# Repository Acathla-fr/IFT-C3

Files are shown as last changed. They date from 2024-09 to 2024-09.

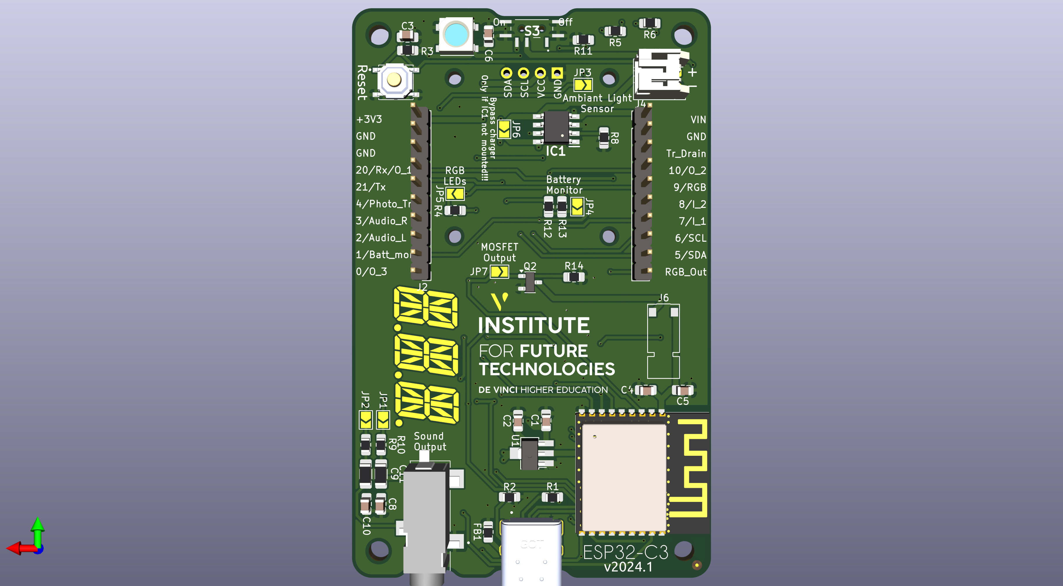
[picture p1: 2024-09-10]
IFT-C3_pcb_back.png

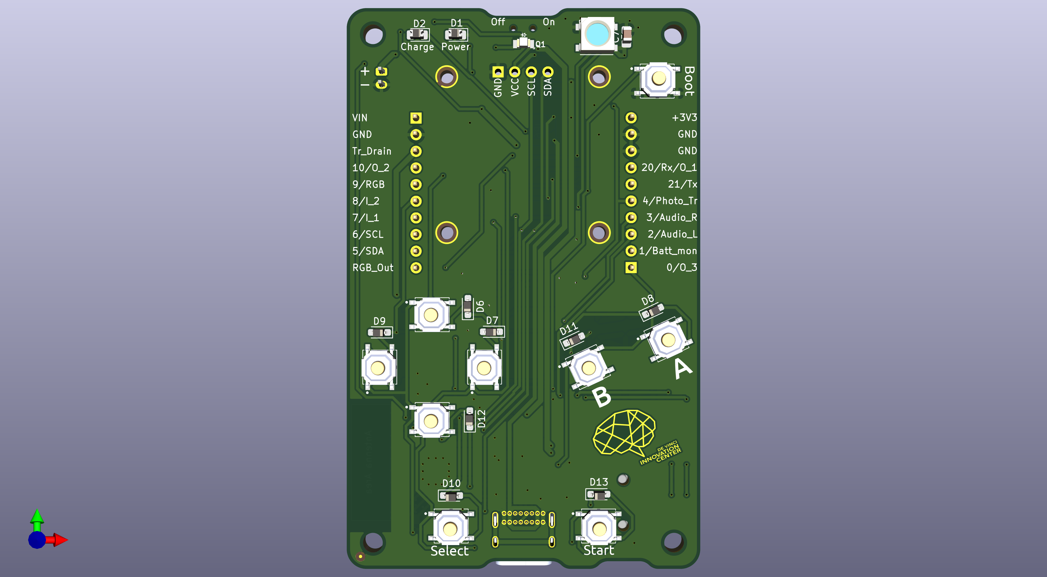
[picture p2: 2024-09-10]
IFT-C3_pcb_front.png

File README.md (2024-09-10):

# IFT-C3
Printed Circuit Board with an ESP32-C3. Version 2.1 (2024)

Version released for the new students. Now integrates the support for the OLED screen and the buttons.

BUGS!!! (fixed in the kicad design, not on the produced boards):

    Buttons pinout is wrong, you'll have to solder them rotated 25°. For the Boot/Start button, since I thought there was two buttons in one without verifying, you'll have to be creative to fix it (at least the start button, the boot can be selected with Dupont wires by connecting pin 9 to ground).
    Holes for the screen are too small, you'll have to replace the connector or be creative (file the pins works).

GPIO 0 is used by the keyboard matrix<br/>
GPIO 1 is used by the keyboard matrix and optionnaly for battery voltage measurement<br/>
GPIO 2 and 3 are optionnaly used for audio<br/>
GPIO 4 is optionnaly used for the light sensor or to control the MOSFET<br/>
GPIO 5 is used by the SDA line for the OLED screen<br/>
GPIO 6 is used by the SCL line for the OLED screen<br/>
GPIO 7 is used by the keyboard matrix<br/>
GPIO 8 is used by the keyboard matrix<br/>
GPIO 9 is plugged to the Boot button which can be used in your design. The reset button cannot.<br/>
GPIO 9 also optionnaly used for the RGBW LEDs<br/>
GPIO 10 is used by the keyboard matrix<br/>
GPIO 20 is used by the keyboard matrix but also as the Rx UART
GPIO 21 is used by Tx UART

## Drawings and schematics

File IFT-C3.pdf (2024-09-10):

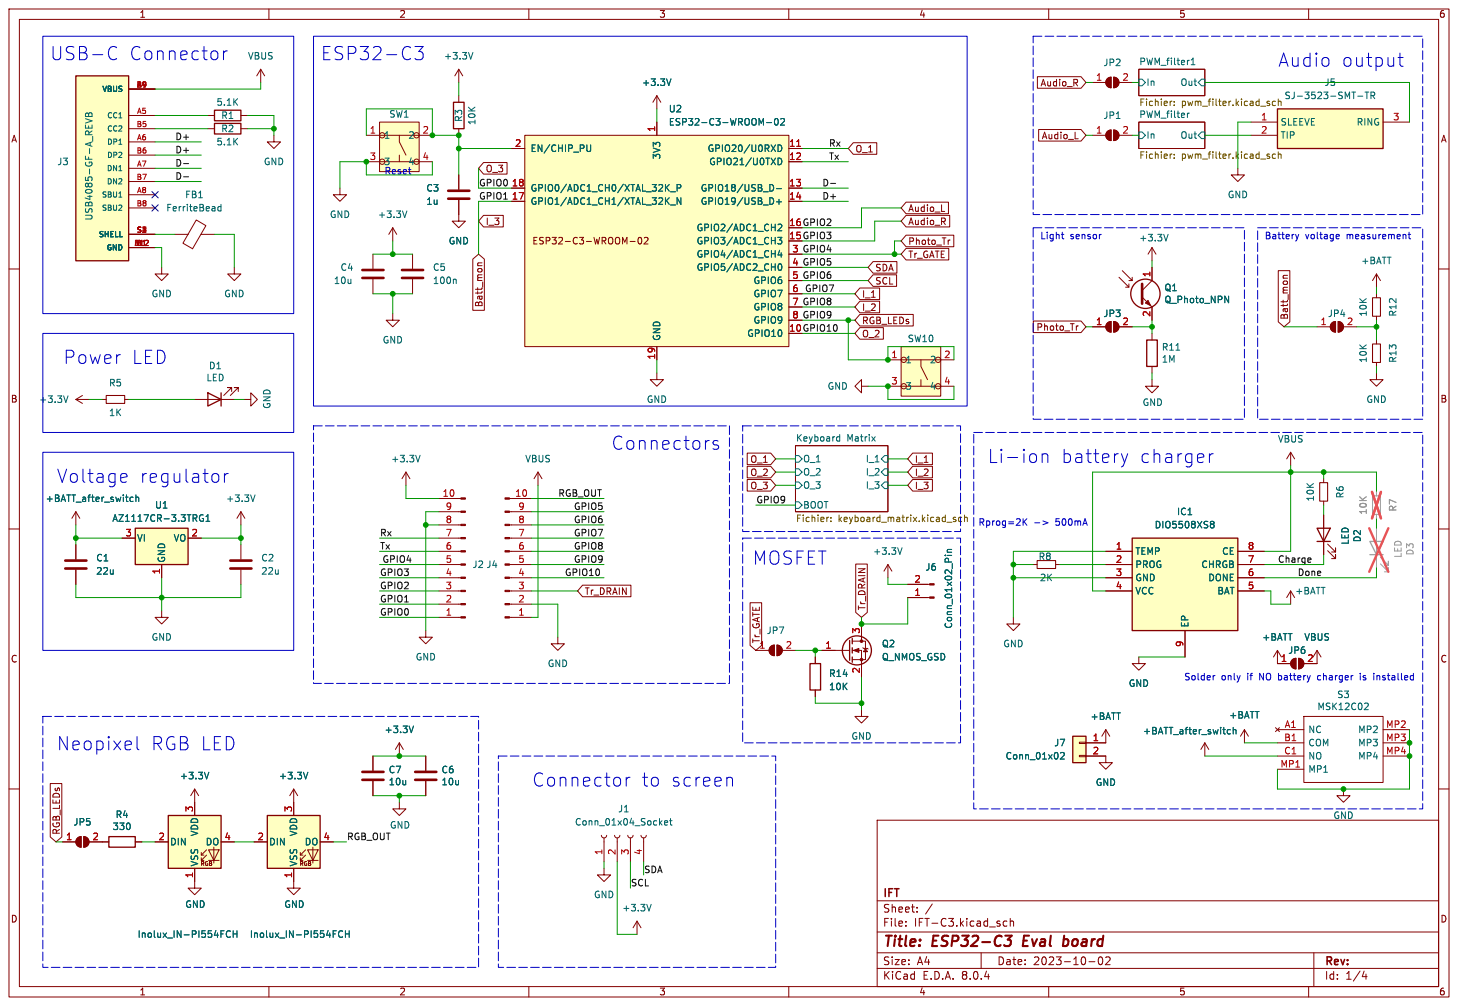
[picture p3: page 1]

J5 SJ-3523-SMT-TR GND

I_1 BOOT Keyboard Matrix Fichier: keyboard_matrix.kicad_sch C4

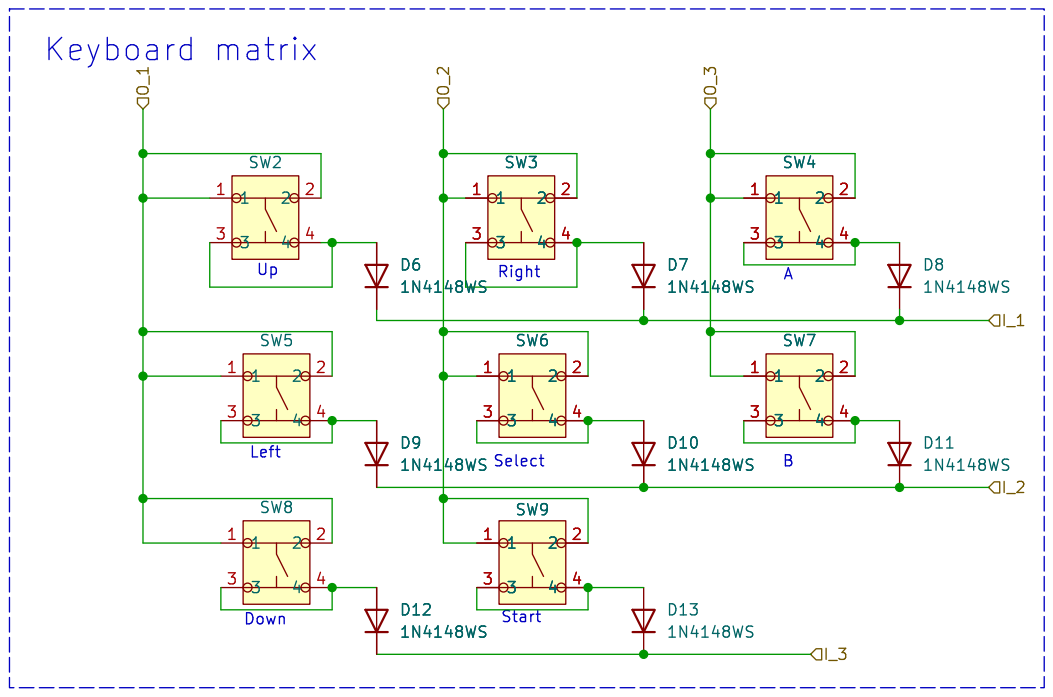
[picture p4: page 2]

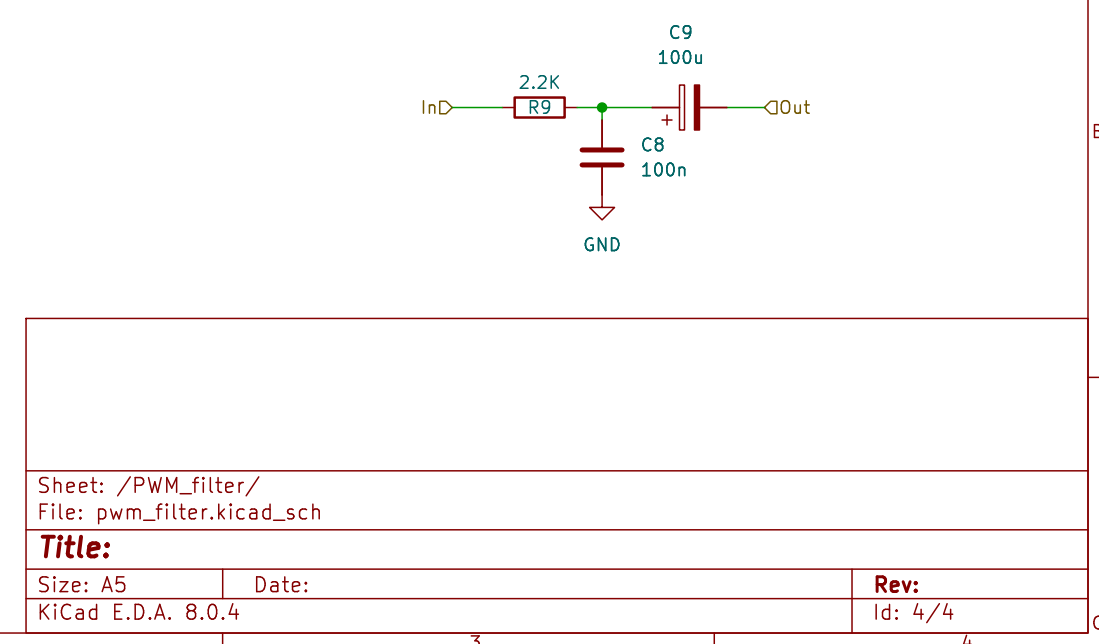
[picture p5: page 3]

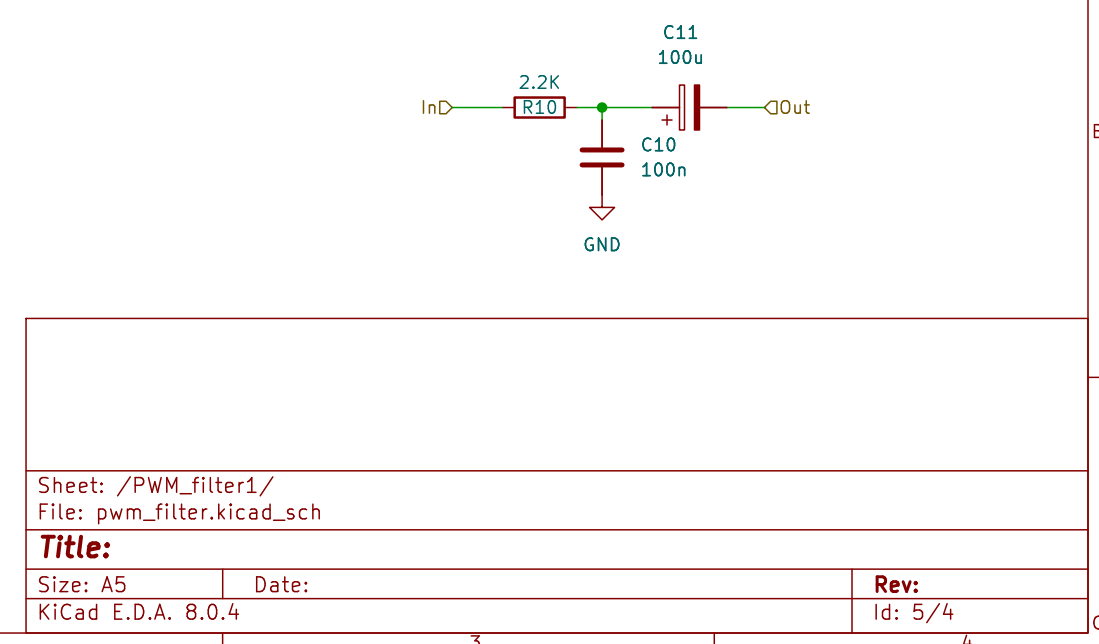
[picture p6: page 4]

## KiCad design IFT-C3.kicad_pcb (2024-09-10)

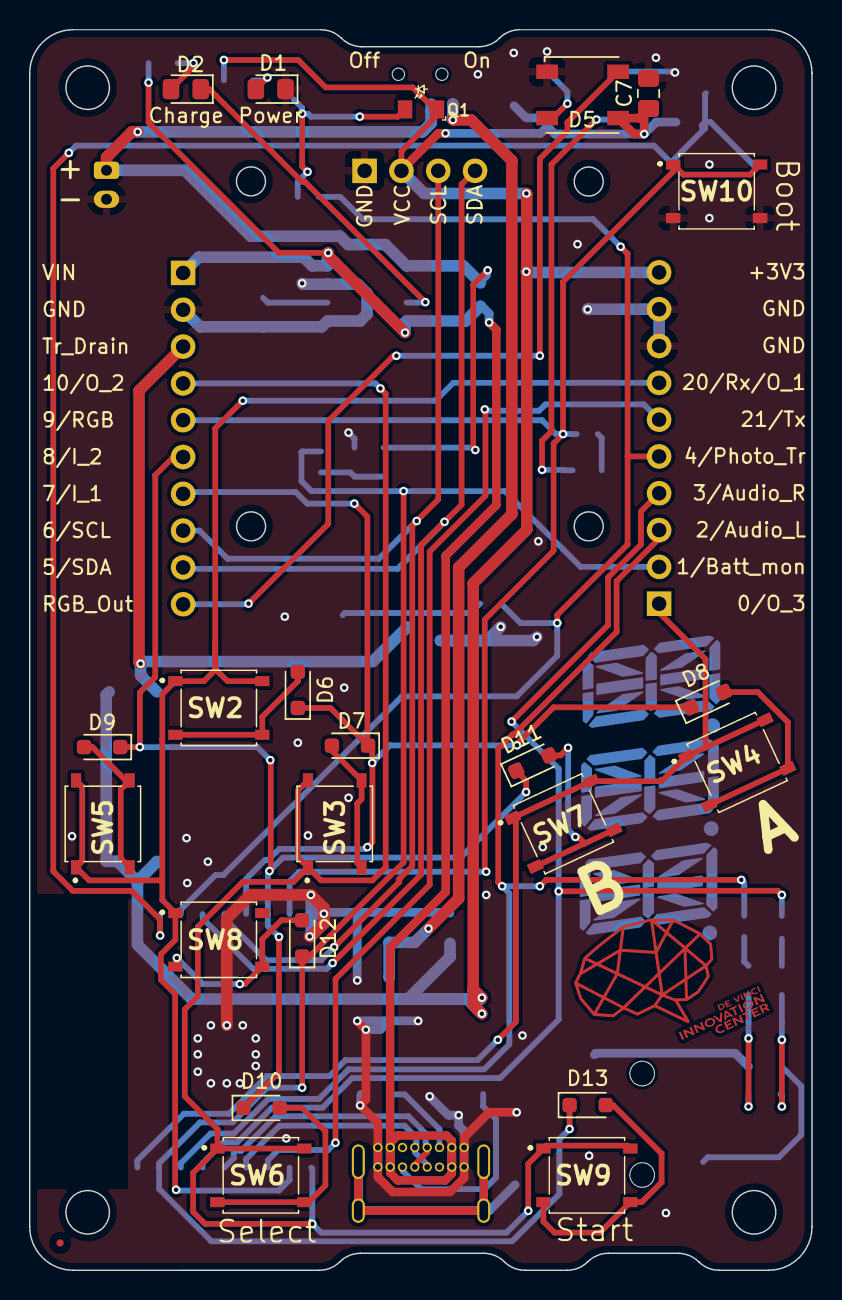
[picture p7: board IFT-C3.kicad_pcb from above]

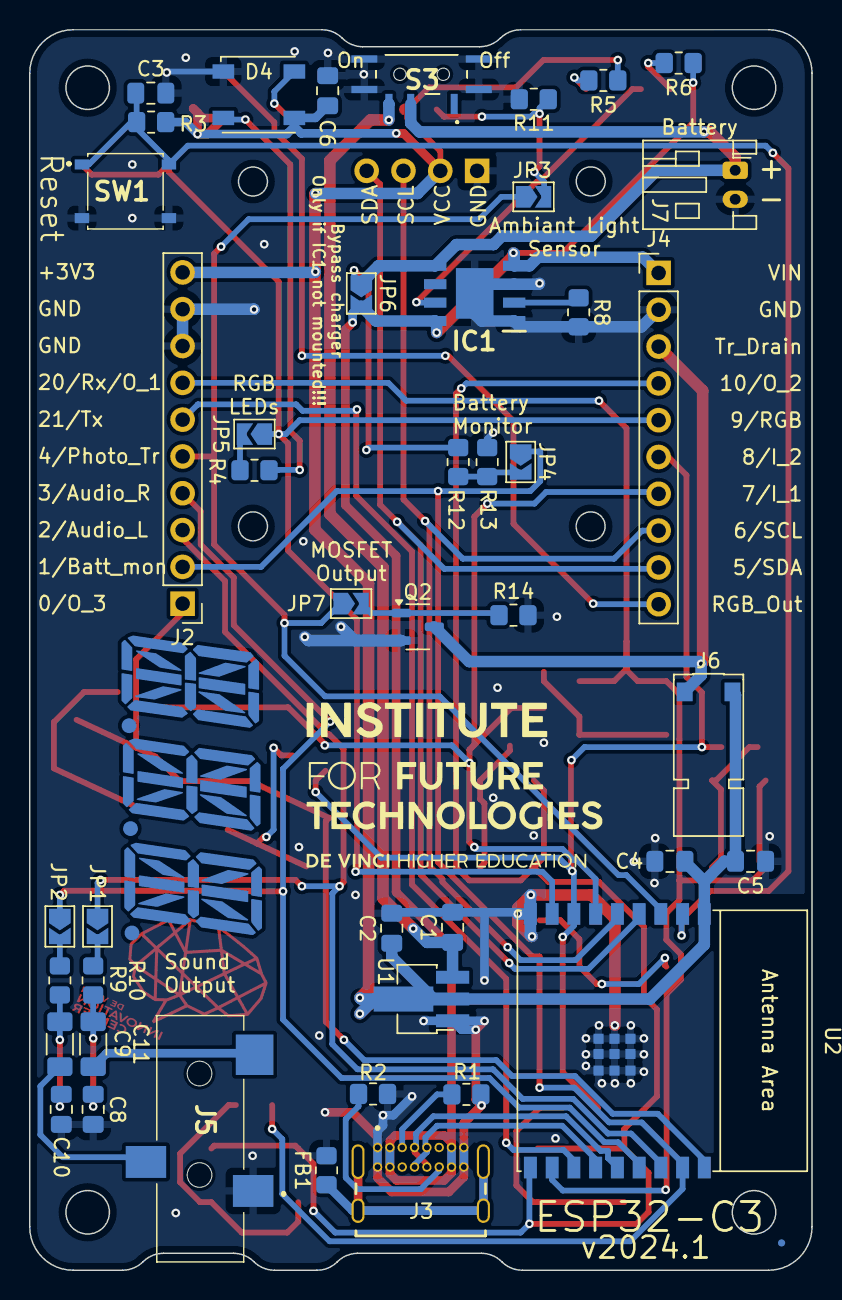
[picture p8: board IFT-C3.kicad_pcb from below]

Board: 2 copper layers, 54.0 x 85.6 mm, 70 parts (47 on the bottom side), 50 nets.

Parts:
C1, C2: 22u; C_0805_2012Metric_Pad1.18x1.45mm_HandSolder
C3: 1u; C_0805_2012Metric_Pad1.18x1.45mm_HandSolder
C4, C6, C7: 10u; C_0805_2012Metric_Pad1.18x1.45mm_HandSolder
C5, C8, C10: 100n; C_0805_2012Metric_Pad1.18x1.45mm_HandSolder
C9, C11: 100u; R_1206_3216Metric_Pad1.30x1.75mm_HandSolder
D1, D2: LED; D_0805_2012Metric_Pad1.15x1.40mm_HandSolder
D4, D5: Inolux_IN-PI554FCH; LED_Inolux_IN-PI554FCH_PLCC4_5.0x5.0mm_P3.2mm
D6, D7, D8, D9, D10, D11, D12, D13: 1N4148WS; D_SOD-323_HandSoldering
FB1: FerriteBead; R_0805_2012Metric_Pad1.20x1.40mm_HandSolder
G001, G001#2, G001#3: LOGO; segments
IC1: DIO5508XS8; SOIC127P600X170-9N
J1: Conn_01x04_Socket; SSD1306_module
J2, J4: Conn_01x10_Pin; PinHeader_1x10_P2.54mm_Vertical
J3: USB4085-GF-A_REVB; GCT_USB4085-GF-A_REVB
J5: SJ-3523-SMT-TR; SJ3523SMTTR
J6: Conn_01x02_Pin; Vybronics_VZ30C1T8219732L
J7: Conn_01x02; JST_PH_S2B-PH-K_1x02_P2.00mm_Horizontal
JP1, JP2, JP3, JP4, JP5, JP6, JP7: SolderJumper_2_Open; SolderJumper-2_P1.3mm_Open_TrianglePad1.0x1.5mm
Q1: Q_Photo_NPN; SFH3710
Q2: Q_NMOS_GSD; SOT-23-3
R1, R2: 5.1K; R_0805_2012Metric_Pad1.20x1.40mm_HandSolder
R3, R6, R12, R13, R14: 10K; R_0805_2012Metric_Pad1.20x1.40mm_HandSolder
R4: 330; R_0805_2012Metric_Pad1.20x1.40mm_HandSolder
R5: 1K; R_0805_2012Metric_Pad1.20x1.40mm_HandSolder
R8: 2K; R_0805_2012Metric_Pad1.20x1.40mm_HandSolder
R9, R10: 2.2K; R_0805_2012Metric_Pad1.20x1.40mm_HandSolder
R11: 1M; R_0805_2012Metric_Pad1.20x1.40mm_HandSolder
S3: MSK12C02
SW1, SW2, SW3, SW4, SW5, SW6, SW7, SW8, SW9, SW10: PTS526_SK15_SMTR2_LFS; PTS526SK15SMTR2LFS
U1: AZ1117CR-3.3TRG1; SOT-89-3_Handsoldering
U2: ESP32-C3-WROOM-02

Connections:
+3.3V: C2.1, C4.1, C5.1, C6.1, C7.1, D4.3 (VDD), D5.3 (VDD), J1.2, J2.10, J6.2, Q1.1 (C), R3.2, R5.1, U1.2 (VO), U2.1 (3V3)
+BATT: IC1.5 (BAT), J7.1, JP6.1 (A), R12.1, S3.B1 (COM)
+BATT_after_switch: C1.1, S3.C1 (NO), U1.3 (VI)
/Charge: D2.1 (K), IC1.7 (CHRGB)
/D+: J3.A6 (DP1), J3.B6 (DP2), U2.14 (GPIO19/USB_D+)
/D-: J3.A7 (DN1), J3.B7 (DN2), U2.13 (GPIO18/USB_D-)
/PWM_filter1/In: JP2.2 (B), R10.2
/PWM_filter1/Out: C11.2, J5.3 (RING)
/PWM_filter/In: JP1.2 (B), R9.2
/PWM_filter/Out: C9.2, J5.2 (TIP)
/RGB_OUT: D5.4 (DO), J4.10
/Tx: J2.6, U2.12 (GPIO21/U0TXD)
Audio_L: J2.3, JP1.1 (A), U2.16 (GPIO2/ADC1_CH2)
Audio_R: J2.4, JP2.1 (A), U2.15 (GPIO3/ADC1_CH3)
Batt_mon: D12.1 (K), D13.1 (K), J2.2, JP4.1 (A), U2.17 (GPIO1/ADC1_CH1/XTAL_32K_N)
GND: C1.2, C2.2, C3.2, C4.2, C5.2, C6.2, C7.2, C8.2, C10.2, D1.1 (K), D4.1 (VSS), D5.1 (VSS), FB1.2, IC1.1 (TEMP), IC1.3 (GND), IC1.9 (EP), J1.1, J2.8, J2.9, J3.A1 (GND), J3.A12 (GND), J3.B1 (GND), J3.B12 (GND), J4.2, J5.1 (SLEEVE), J7.2, Q2.2 (S), R1.1, R2.2, R8.1, R11.2, R13.2, R14.2, S3.MP1, S3.MP2, S3.MP3, S3.MP4, SW1.3, SW1.4, SW10.3, SW10.4, U1.1 (GND), U2.9 (GND), U2.19 (GND)
I_1: D6.1 (K), D7.1 (K), D8.1 (K), J4.7, U2.6 (GPIO7)
I_2: D9.1 (K), D10.1 (K), D11.1 (K), J4.6, U2.7 (GPIO8)
unnamed: C8.1, C9.1, R9.1
unnamed: C10.1, C11.1, R10.1
unnamed: D1.2 (A), R5.2
unnamed: D2.2 (A), R6.2
unnamed: D4.2 (DIN), R4.1
unnamed: D4.4 (DO), D5.2 (DIN)
unnamed: D6.2 (A), SW2.3, SW2.4
unnamed: D7.2 (A), SW3.3, SW3.4
unnamed: D8.2 (A), SW4.3, SW4.4
unnamed: D9.2 (A), SW5.3, SW5.4
unnamed: D10.2 (A), SW6.3, SW6.4
unnamed: D11.2 (A), SW7.3, SW7.4
unnamed: D12.2 (A), SW8.3, SW8.4
unnamed: D13.2 (A), SW9.3, SW9.4
unnamed: FB1.1, J3.S1 (SHELL), J3.S2 (SHELL), J3.S3 (SHELL), J3.S4 (SHELL)
unnamed: IC1.2 (PROG), R8.2
unnamed: J3.A5 (CC1), R1.2
unnamed: J3.B5 (CC2), R2.1
unnamed: JP3.2 (B), Q1.2 (E), R11.1
unnamed: JP4.2 (B), R12.2, R13.1
unnamed: JP5.2 (B), R4.2
unnamed: JP7.2 (B), Q2.1 (G), R14.1
unnamed: C3.1, R3.1, SW1.1, SW1.2, U2.2 (EN/CHIP_PU)
O_1: J2.7, SW2.1, SW2.2, SW5.1, SW5.2, SW8.1, SW8.2, U2.11 (GPIO20/U0RXD)
O_2: J4.4, SW3.1, SW3.2, SW6.1, SW6.2, SW9.1, SW9.2, U2.10 (GPIO10)
O_3: J2.1, SW4.1, SW4.2, SW7.1, SW7.2, U2.18 (GPIO0/ADC1_CH0/XTAL_32K_P)
Photo_Tr: J2.5, JP3.1 (A), JP7.1 (A), U2.3 (GPIO4/ADC1_CH4)
RGB_LEDs: J4.5, JP5.1 (A), SW10.1, SW10.2, U2.8 (GPIO9)
SCL: J1.3, J4.8, U2.5 (GPIO6)
SDA: J1.4, J4.9, U2.4 (GPIO5/ADC2_CH0)
Tr_DRAIN: J4.3, J6.1, Q2.3 (D)
VBUS: IC1.4 (VCC), IC1.8 (CE), J3.A4 (VBUS), J3.A9 (VBUS), J3.B4 (VBUS), J3.B9 (VBUS), J4.1, JP6.2 (B), R6.1

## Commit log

2023-10-05 board almost as sent for production to PCBWay
    [IFT-C3.kicad_pcb, IFT-C3.kicad_sch, button.kicad_sch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]
2023-11-21 erratum on GPIO silkscreen for RX and TX
2024-01-03 Dynamic BOM added
2024-06-27 WIP v2024
    [IFT-C3.kicad_pcb, IFT-C3.kicad_sch, keyboard_matrix.kicad_sch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]
2024-07-02 Precision added to the 3V3 regulator's reference
    [IFT-C3.kicad_sch]
2024-07-10 WIP, routed
    [IFT-C3.kicad_pcb, IFT-C3.kicad_sch, pwm_filter.kicad_sch]
2024-07-11 holes cleared
    [IFT-C3.kicad_pcb]
2024-07-17 RGB LEDs moved, almost ready for prob
    [IFT-C3.kicad_pcb, IFT-C3.kicad_sch]
2024-08-20 Version sent to Aisler
    [IFT-C3.kicad_pcb]
2024-08-21 Uniformed values for R and C for a better BOM
    [IFT-C3.kicad_pcb, IFT-C3.kicad_sch, pwm_filter.kicad_sch]
2024-09-10 Bugs fixed (buttons and OLED holes)
    [IFT-C3.kicad_pcb, IFT-C3.kicad_sch, keyboard_matrix.kicad_sch]
2024-09-10 Buttons fixed, boot buuton added, footprint of the switch should be easier to solder by hand
    [IFT-C3.kicad_pcb, IFT-C3.kicad_sch]
